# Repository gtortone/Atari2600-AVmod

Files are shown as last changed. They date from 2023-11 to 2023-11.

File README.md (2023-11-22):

# Atari2600-AVmod
Atari 2600 AV mod based on Longhorn A/V mod

## Bill of material

|Qty|Ref|Value|LibPart|Footprint|
|---|---|-----|---|---|
|1|C1|100uF|Device:C_Polarized|Capacitor_THT:CP_Radial_D5.0mm_P2.00mm|
|1|C2|1uF|Device:C_Polarized|Capacitor_THT:CP_Radial_D4.0mm_P2.00mm|
|1|C3|10uF|Device:C|Capacitor_THT:C_Disc_D4.7mm_W2.5mm_P5.00mm|
|2|C4, C5|.1uF|Device:C|Capacitor_THT:C_Disc_D4.7mm_W2.5mm_P5.00mm|
|1|D1|1N914|Diode:1N914|Diode_THT:D_DO-35_SOD27_P7.62mm_Horizontal|
|1|Q1|2N3904|Transistor_BJT:2N3904|Package_TO_SOT_THT:TO-92_Inline|
|1|R1|1k|Device:R|Resistor_THT:R_Axial_DIN0207_L6.3mm_D2.5mm_P10.16mm_Horizontal|
|1|R2|1.8k|Device:R|Resistor_THT:R_Axial_DIN0207_L6.3mm_D2.5mm_P10.16mm_Horizontal|
|1|R3|1.5k|Device:R|Resistor_THT:R_Axial_DIN0207_L6.3mm_D2.5mm_P10.16mm_Horizontal|
|1|R4|18k|Device:R|Resistor_THT:R_Axial_DIN0207_L6.3mm_D2.5mm_P10.16mm_Horizontal|
|1|R5|9.1k|Device:R|Resistor_THT:R_Axial_DIN0207_L6.3mm_D2.5mm_P10.16mm_Horizontal|
|1|R6|36k|Device:R|Resistor_THT:R_Axial_DIN0207_L6.3mm_D2.5mm_P10.16mm_Horizontal|
|1|R7|1.6k|Device:R|Resistor_THT:R_Axial_DIN0207_L6.3mm_D2.5mm_P10.16mm_Horizontal|
|1|R8|2k|Device:R|Resistor_THT:R_Axial_DIN0207_L6.3mm_D2.5mm_P10.16mm_Horizontal|
|1|R9|10|Device:R|Resistor_THT:R_Axial_DIN0207_L6.3mm_D2.5mm_P10.16mm_Horizontal||
|10|R10, R11, R12, R13, R14, R15, R16, R17, R18, R19|75|Device:R|Resistor_THT:R_Axial_DIN0207_L6.3mm_D2.5mm_P10.16mm_Horizontal|
|1|U1|CD74HC4050|4xxx:4050|Package_DIP:DIP-16_W7.62mm|
|1|U2|FMS6410|Video_filter:FMS6410|Package_SO:SOIC-8_3.9x4.9mm_P1.27mm|

## Schematic and PCB

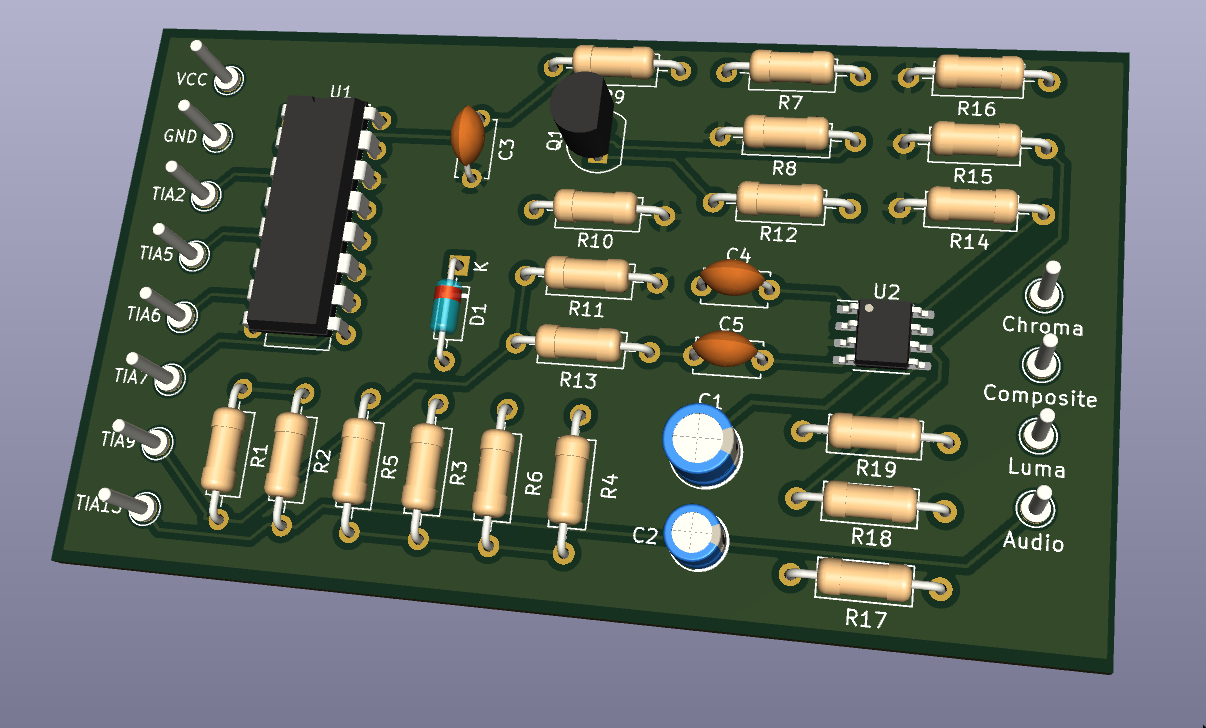
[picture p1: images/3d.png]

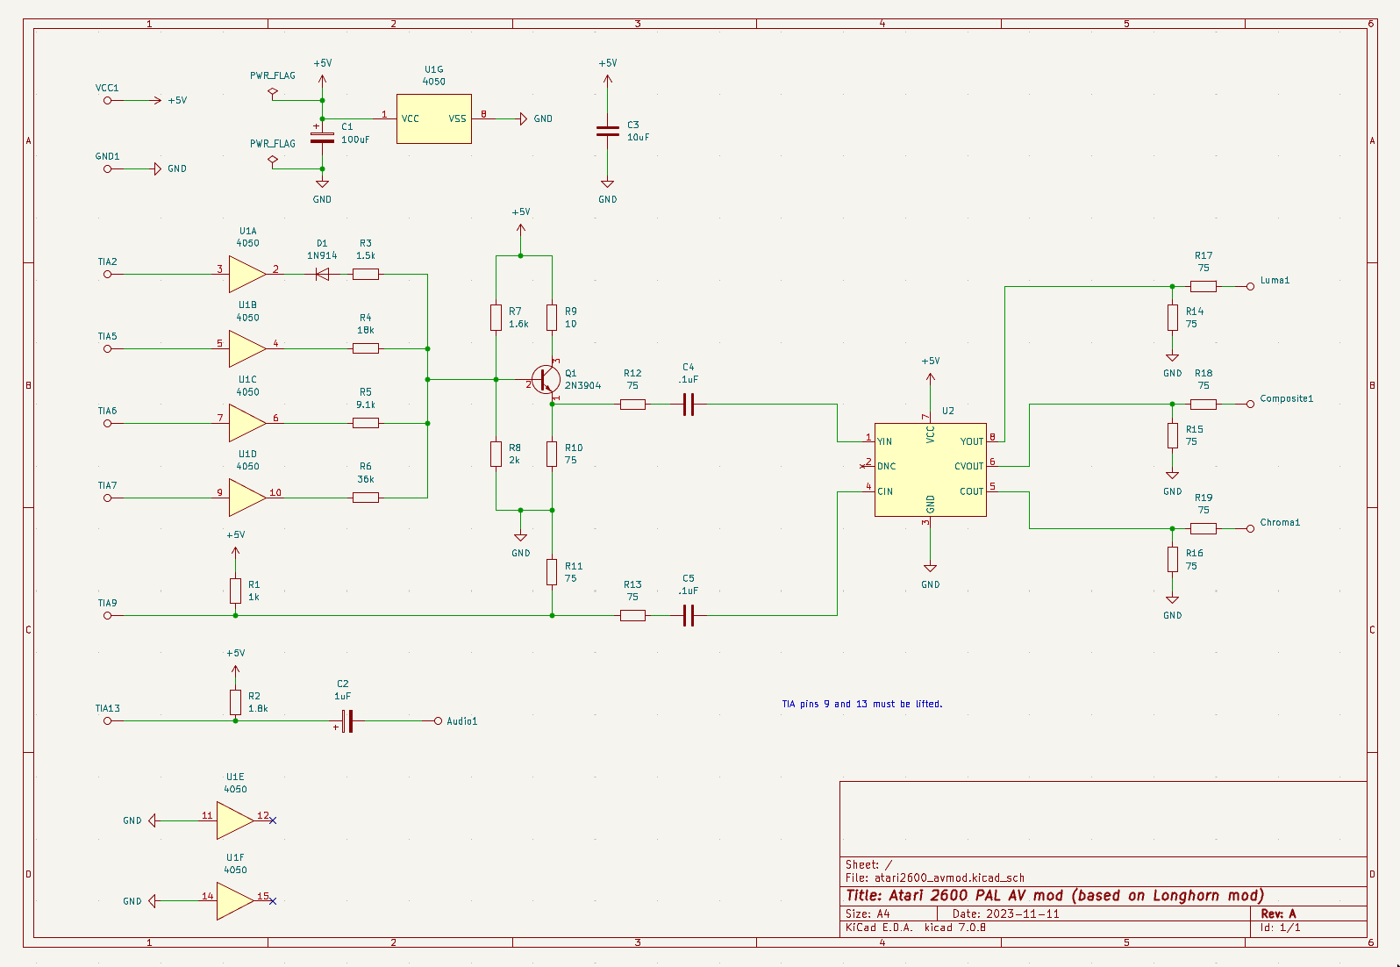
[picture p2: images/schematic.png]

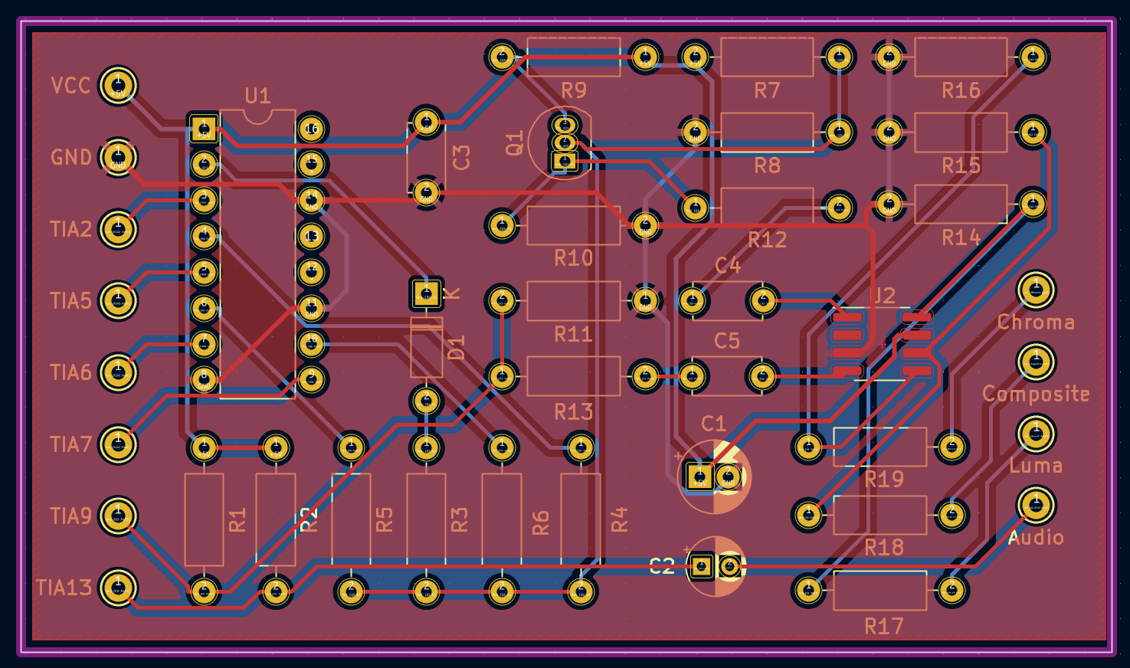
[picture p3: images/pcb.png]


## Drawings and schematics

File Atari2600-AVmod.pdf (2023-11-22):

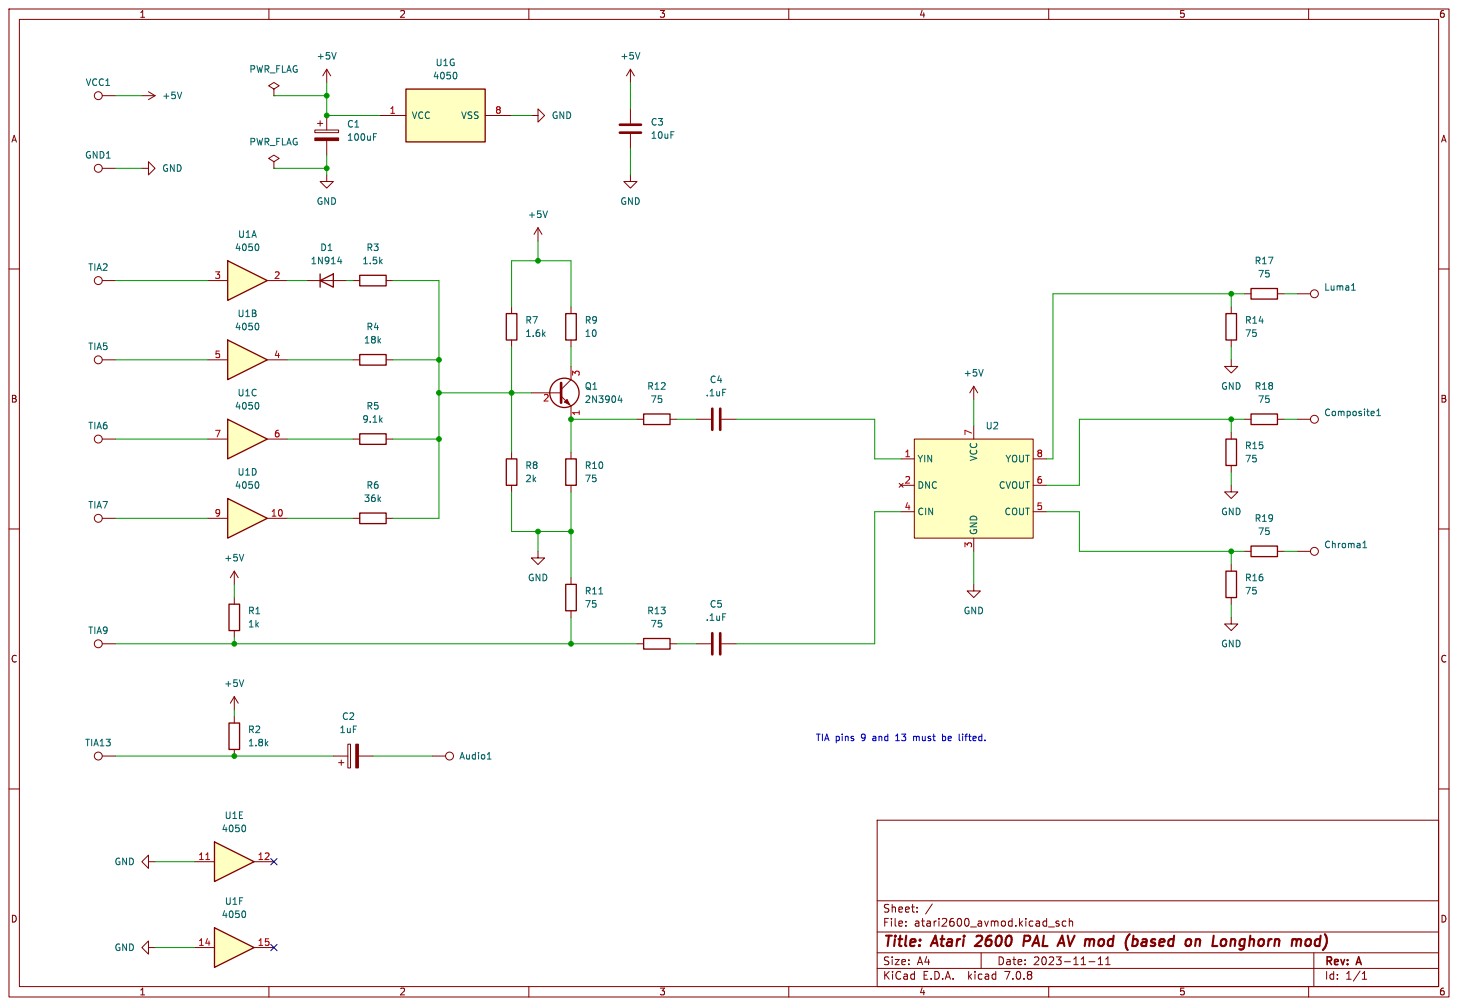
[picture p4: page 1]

3 CIN 4 COUT 5 CVOUT 6 VCC

TIA pins 9 and 13 must be lifted.

Id: 1/1 Title: Atari 2600 PAL AV mod (based on Longhorn mod) File: atari2600_avmod.kicad_sch Sheet: /

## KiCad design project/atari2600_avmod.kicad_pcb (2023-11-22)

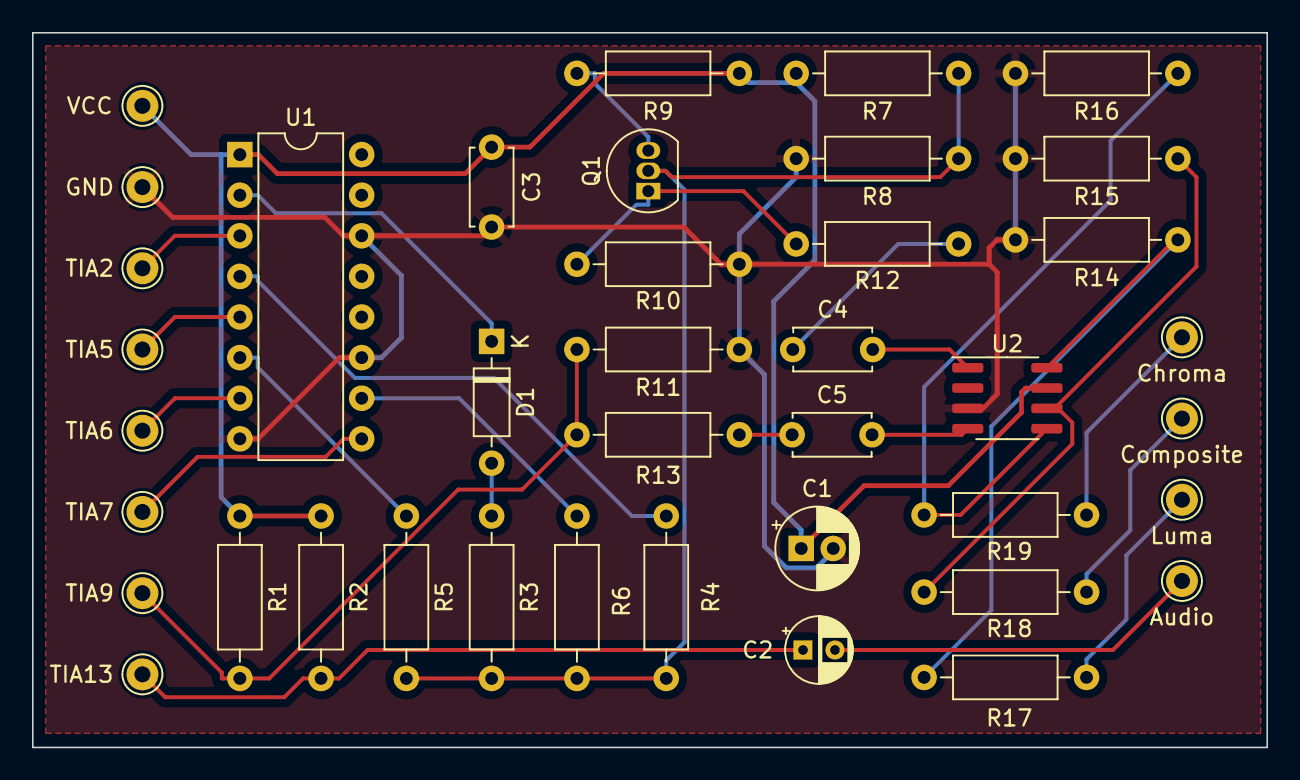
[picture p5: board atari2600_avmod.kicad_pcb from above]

Board: 2 copper layers, 77.2 x 44.7 mm, 40 parts (0 on the bottom side), 27 nets.

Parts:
Audio: Pin_D1.0mm_L10.0mm
C1: 100uF; CP_Radial_D5.0mm_P2.00mm
C2: 1uF; CP_Radial_D4.0mm_P2.00mm
C3: 10uF; C_Disc_D4.7mm_W2.5mm_P5.00mm
C4, C5: .1uF; C_Disc_D4.7mm_W2.5mm_P5.00mm
Chroma: Pin_D1.0mm_L10.0mm
Composite: Pin_D1.0mm_L10.0mm
D1: 1N914; D_DO-35_SOD27_P7.62mm_Horizontal
GND: Pin_D1.0mm_L10.0mm
Luma: Pin_D1.0mm_L10.0mm
Q1: 2N3904; TO-92_Inline
R1: 1k; R_Axial_DIN0207_L6.3mm_D2.5mm_P10.16mm_Horizontal
R2: 1.8k; R_Axial_DIN0207_L6.3mm_D2.5mm_P10.16mm_Horizontal
R3: 1.5k; R_Axial_DIN0207_L6.3mm_D2.5mm_P10.16mm_Horizontal
R4: 18k; R_Axial_DIN0207_L6.3mm_D2.5mm_P10.16mm_Horizontal
R5: 9.1k; R_Axial_DIN0207_L6.3mm_D2.5mm_P10.16mm_Horizontal
R6: 36k; R_Axial_DIN0207_L6.3mm_D2.5mm_P10.16mm_Horizontal
R7: 1.6k; R_Axial_DIN0207_L6.3mm_D2.5mm_P10.16mm_Horizontal
R8: 2k; R_Axial_DIN0207_L6.3mm_D2.5mm_P10.16mm_Horizontal
R9: 10; R_Axial_DIN0207_L6.3mm_D2.5mm_P10.16mm_Horizontal
R10, R11, R12, R13, R14, R15, R16, R17, R18, R19: 75; R_Axial_DIN0207_L6.3mm_D2.5mm_P10.16mm_Horizontal
TIA2, TIA5, TIA6, TIA7, TIA9, TIA13: Pin_D1.0mm_L10.0mm
U1: 4050; DIP-16_W7.62mm
U2: SOIC-8_3.9x4.9mm_P1.27mm
VCC: Pin_D1.0mm_L10.0mm

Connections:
+5V: C1.1, C3.1, R1.1, R2.1, R7.2, R9.1, U1.1 (VCC), U2.7 (VCC), VCC.1
GND: C1.2, C3.2, GND.1, R8.2, R10.2, R11.1, R14.2, R15.2, R16.2, U1.8 (VSS), U1.11, U1.14, U2.3 (GND)
unnamed: Audio.1, C2.2
unnamed: C2.1, R2.2, TIA13.1
unnamed: C4.1, R12.2
unnamed: C5.1, R13.2
unnamed: Chroma.1, R19.2
unnamed: Composite.1, R18.2
unnamed: D1.2 (A), R3.1
unnamed: D1.1 (K), U1.2
unnamed: Luma.1, R17.2
unnamed: Q1.2 (B), R3.2, R4.2, R5.2, R6.2, R7.1, R8.1
unnamed: Q1.3 (C), R9.2
unnamed: Q1.1 (E), R10.1, R12.1
unnamed: R1.2, R11.2, R13.1, TIA9.1
unnamed: R4.1, U1.4
unnamed: R5.1, U1.6
unnamed: R6.1, U1.10
unnamed: TIA2.1, U1.3
unnamed: TIA5.1, U1.5
unnamed: TIA6.1, U1.7
unnamed: TIA7.1, U1.9
unnamed: C5.2, U2.4 (CIN)
unnamed: R16.1, R19.1, U2.5 (COUT)
unnamed: R15.1, R18.1, U2.6 (CVOUT)
unnamed: C4.2, U2.1 (YIN)
unnamed: R14.1, R17.1, U2.8 (YOUT)
